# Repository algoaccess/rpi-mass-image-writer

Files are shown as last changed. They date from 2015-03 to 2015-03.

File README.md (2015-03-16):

# rpi-mass-image-writer
Raspberry Pi that writes to many USB drives at one go. Hardware buttons available to select the stored disk image to copy as well as to shutdown the device. 

Disk images are transferred to the Raspberry Pi via a Samba shared folder. The selected image is then written in parallel to all the drives at once using the ```dd```, ```pv``` and ```tee``` commands 

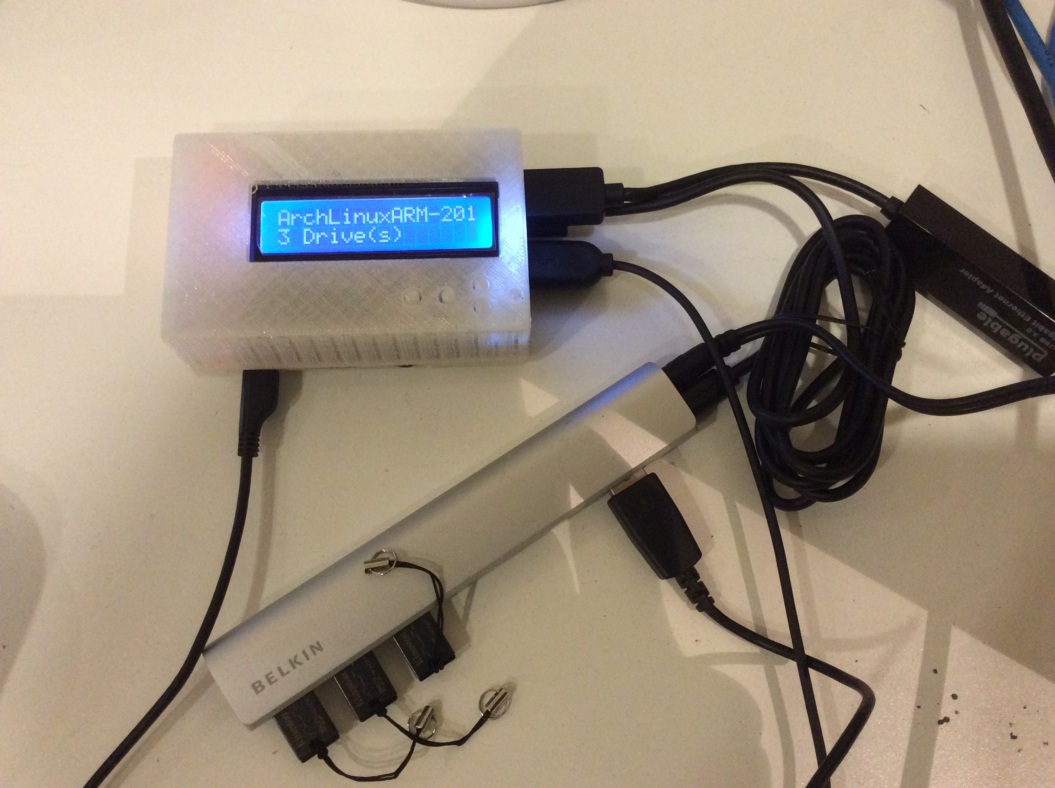
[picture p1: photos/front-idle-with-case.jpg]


Everything in with a nice 3D printed case.

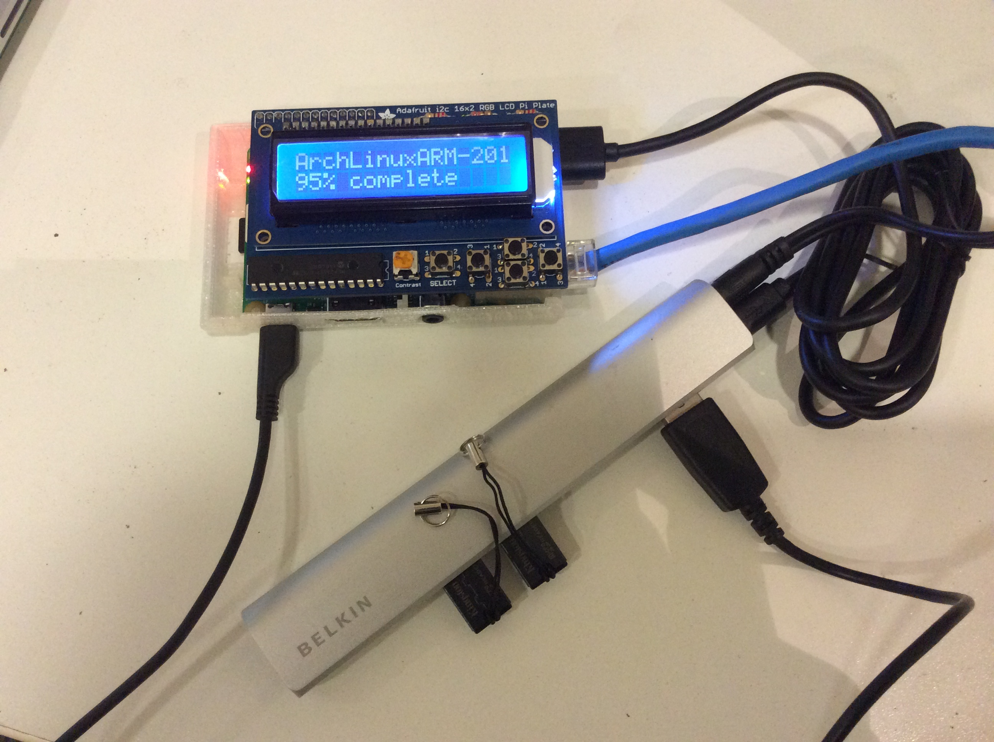
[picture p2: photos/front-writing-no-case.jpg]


The innards

#How to use?
1. Login to shared folder
2. Transfer image files via samba to shared folder
3. Plug in all USB flash drives to write to
4. Hit left button to enumerate all images and drives 
5. Use up/down buttons to select image
6. Press the right button to start writing to drives. You can press it again to terminate writing.
7. Press the select button (extreme left) to shutdown device properly to prevent data corruption. The words "Shutting down" will remain even after the device has completely shutdown, so just wait for the activity light to turn off before pulling the power.

#Hardware
1. Raspberry Pi 2 Model B (Others will work just as well)
2. Adafruit i2c 16x2 LCD Pi Plate with keypad
3. USB hubs (not all hubs are supported well, use the ones from this [list](http://elinux.org/RPi_Powered_USB_Hubs))
4. USB SD card adapters
5. USB Gigabit adapter (optional)

#Setting up

I use Arch Linux as it is stripped down and boots up far faster than Raspbian. With some modifications to the setup instructions, you can run this on Raspbian as well.

##Installing packages and configuring i2C

```bash
pacman -Syu python2 i2c-tools samba pv git

modprobe i2c-dev
echo "i2c-dev" > /etc/modules-load.d/i2c-dev.conf
```

On the latest versions of Arch Linux, it seems the i2c bus is disabled by default. We have to enable it. [Source](http://archlinuxarm.org/forum/viewtopic.php?f=31&t=8330)

```bash
nano /boot/config.txt

#Add the following lines
#Start
#If needed, replace the value below with "bcm2708-rpi-b.dtb" or "bcm2708-rpi-b-plus.dtb" depending on your Raspberry Pi type.
device_tree=bcm2709-rpi-2-b.dtb 
device_tree_param=i2c1=on
device_tree_param=spi=on
#End

reboot
```

##Clone this repo and run the app

```bash
git clone https://github.com/algoaccess/rpi-mass-image-writer.git
cd rpi-mass-image-writer
python2 writer.py
```
The LCD screen should now turn on.

##Setting up samba 

The folder we are sharing is the images directory.

```bash
nano /etc/samba/smb.conf
#Add/Modify the following lines to your smb.conf file between #start and #end
#Start
[global]
workgroup = WORKGROUP
server string = SD Duplicator
security = user
log file = /var/log/samba/%m.log
max log size = 50
dns proxy = no

[images]
path = /root/rpi-mass-image-writer/images
writable = yes
#End

#Create a user for samba
smbpasswd -a root
systemctl enable smbd
```

##Change hostname (optional)

In case you don't like the default ```alarmpi``` hostname.

```bash
hostnamectl set-hostname pi-usb-replicator
```

##Using a separate USB Gigabit adapter

Transfering large image files takes a long time on the internal 10/100 adapter so I opted to use a Gigabit adapter instead. Note that Pi is using just USB 2.0 with other devices sharing the bus so the speedup is only just about 2x instead of 10x faster which is still better than previously.

```bash
cp /etc/netctl/examples/ethernet-dhcp /etc/netctl/eth1
nano /etc/netctl/eth1

#Change the "Interface" value from eth0 to eth1

netctl enable eth1
reboot
#Test the network connection
```

##Starting on boot

```bash
cp /root/rpi-mass-image-writer/writer.service /etc/systemd/system/
systemctl enable writer.service
reboot
```

#References
1. [Open Source Image Duplicator](https://github.com/rockandscissor/osid)
2. [Adafruit Char Plate LCD](https://learn.adafruit.com/adafruit-16x2-character-lcd-plus-keypad-for-raspberry-pi/overview)
3. [i2c setup on Arch Linux](http://cfedk.host.cs.st-andrews.ac.uk/site/?q=2013-pi)
4. [Rpi 2 Model B 3D case top](http://www.thingiverse.com/thing:588608)
5. [Rpi 2 Model B 3D case bottom](http://www.thingiverse.com/thing:582366)
6. [Enable i2c on Arch Linux](http://archlinuxarm.org/forum/viewtopic.php?f=31&t=8330)
7. [dd to multiple drives](https://joshhead.wordpress.com/2011/08/04/multiple-output-files-with-dd-utility/)

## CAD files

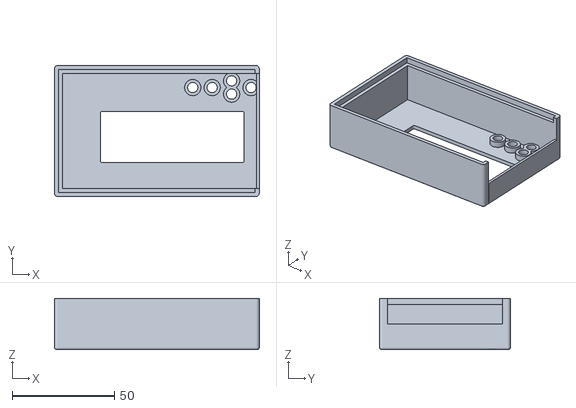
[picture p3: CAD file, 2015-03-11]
case/lcd-cover.stl
100.1 x 64.0 x 25.0

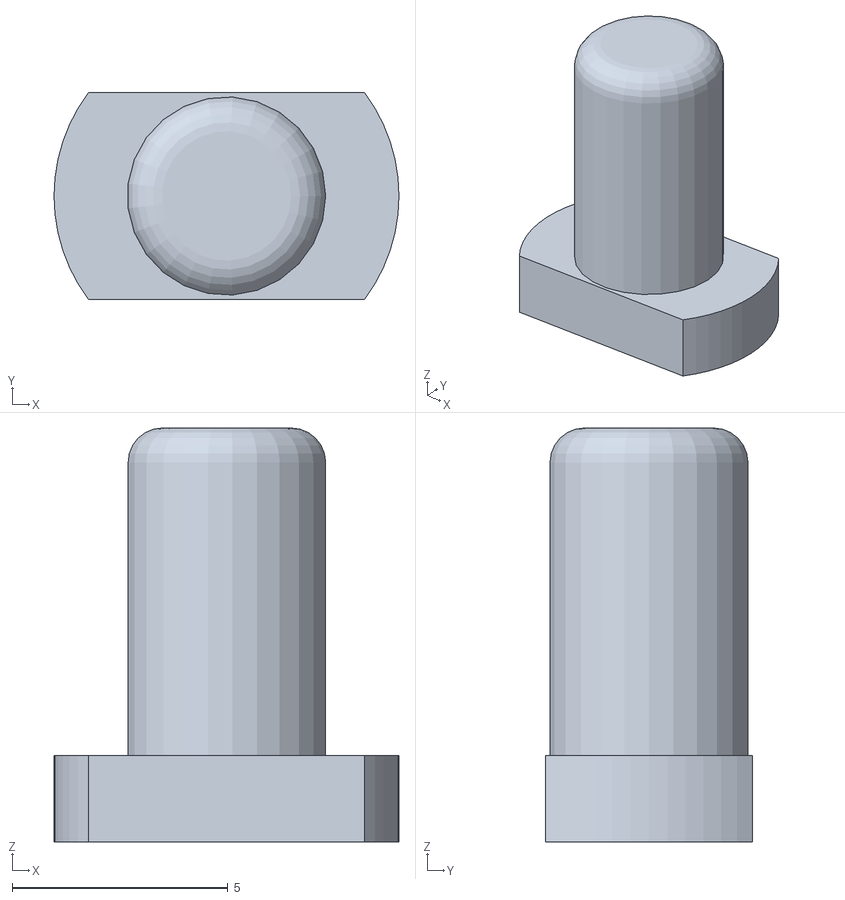
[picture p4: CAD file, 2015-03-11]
case/button.stl
8.00 x 4.80 x 9.60

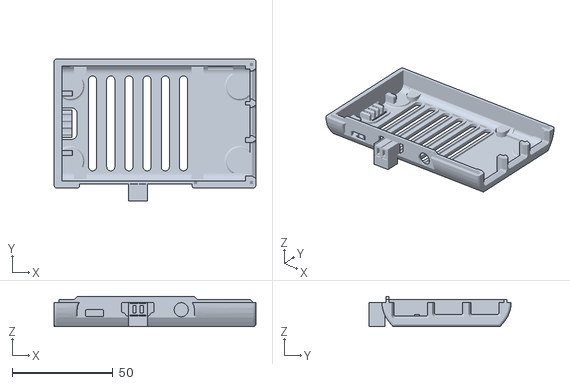
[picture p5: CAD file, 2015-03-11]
case/B+Base-Vented.stl
100.0 x 70.5 x 14.9

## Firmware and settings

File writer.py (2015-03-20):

import time
import shlex
import os
import subprocess
from threading import Thread
from os import listdir
from os.path import isfile, join
from subprocess import Popen, PIPE
from Adafruit_CharLCDPlate import Adafruit_CharLCDPlate

COLUMNS = 16
ROWS = 2
imagePath = "images/"

imageNames = []

currentImageSelection = 0
listOfDrives = []

writeStatusLine = ""

justCompleted = False
nowWriting = False
stopWritingNow = False

lastPressedTime = time.time()

lcd = Adafruit_CharLCDPlate()
lcd.begin(COLUMNS, ROWS)
lcd.clear()

def getConnectedDrives():
    commandOutput = runCommandAndGetStdout("lsblk -d | awk -F: '{print $1}' | awk '{print $1}'")
    splitted = commandOutput.splitlines()

    drives = []

    for drive in splitted:
        if drive != "NAME" and not drive.startswith("mmc"):
            drives.append(drive)
            

    return drives

def powerOff():
    lcd.clear()
    lcd.message("Shutting down...")
    runCommandAndGetStdout("poweroff")



def refreshSystem():
    global imageNames
    global listOfDrives

    filesfound = [ f for f in listdir(imagePath) if isfile(join(imagePath,f)) ]

    imageNames = []
    for file in filesfound:
        if file != ".gitignore":
            imageNames.append(file)


    currentImageSelection = 0;
    listOfDrives = getConnectedDrives()


def refreshLcd():
    numDrives = len(listOfDrives)
    numImages = len(imageNames)

    imageMessage = ""

    if numImages == 0:
        imageMessage = "No images found"
    else:
        imageMessage = imageNames[currentImageSelection]

    lcd.clear()

    driveMessage = ""

    if nowWriting:
        driveMessage = writeStatusLine + "% complete"
    else :
        if justCompleted :
            driveMessage = "Write complete!"
        else :
            driveMessage = str(numDrives) + " Drive(s)"

    lcd.setCursor(0, 0)
    lcd.message(imageMessage[:COLUMNS])
    print imageMessage

    lcd.setCursor(0, 1)
    lcd.message(driveMessage[:COLUMNS])
    print driveMessage




def runCommandAndGetStdout(cmd):
    proc = Popen(cmd, stdout=PIPE, stderr=PIPE, shell=True)
    out, err = proc.communicate()
    return out

def writeThreadFunction(arg):
    global nowWriting
    global writeStatusLine
    global stopWritingNow
    global justCompleted

    process = Popen(arg, stdout=PIPE, stderr=PIPE, shell=True, executable='/bin/bash')
    lines_iterator = iter(process.stderr.readline, b"")
    for line in lines_iterator:

        if stopWritingNow :
            runCommandAndGetStdout("killall pv")
            runCommandAndGetStdout("killall dd")
            process.kill()
            break


        line = line.rstrip()
        
        if line == "100" :
            line = "99" #To not give the impression that write has completed as the value stays at 100% for some time

        if writeStatusLine != line:
            writeStatusLine = line
            refreshLcd()



    if stopWritingNow :
        stopWritingNow = False
        justCompleted = False
    else :
        justCompleted = True

    nowWriting = False
    refreshLcd()


def writeImage():

    global nowWriting
    global writeStatusLine
    global stopWritingNow

    if len(imageNames) == 0 or len(listOfDrives) == 0:
        return

    imagingCommand = constructCommand()

    nowWriting = True
    stopWritingNow = False

    writeStatusLine = "0"
    refreshLcd()

    thread = Thread(target = writeThreadFunction, args = (imagingCommand, ))
    thread.start()




def constructCommand():
    command = "pv -n " + imagePath + "\"" +  imageNames[currentImageSelection] +  "\""
    numDrives = len(listOfDrives)

    firstDriveName = listOfDrives[0]
    firstDriveCommand = " | dd of=/dev/" + firstDriveName + " bs=1M"


    for i in range(1, numDrives):
        nextDriveCommand = " | tee >(dd of=/dev/" + listOfDrives[i] + " bs=1M)"
        command += nextDriveCommand


    command += firstDriveCommand
    print command
    return command



refreshSystem()
refreshLcd()

while True:
    time.sleep(0.01) #To prevent excessive CPU use
    currentTime = time.time()
    
    if (currentTime - lastPressedTime) >= 0.2:

        if lcd.buttonPressed(lcd.UP):
            lastPressedTime = currentTime
            
            if nowWriting :
                stopWritingNow = True
                continue


            if justCompleted :
                justCompleted = False
                continue
        
            currentImageSelection += 1
                
            if currentImageSelection >= len(imageNames):
                currentImageSelection = 0
            
            refreshLcd()

        elif lcd.buttonPressed(lcd.DOWN):
            lastPressedTime = currentTime
            
            if nowWriting :
                stopWritingNow = True
                continue

            if justCompleted :
                justCompleted = False
                continue

            currentImageSelection -= 1
        
            if currentImageSelection < 0:
                currentImageSelection = len(imageNames) - 1

            refreshLcd()


        if lcd.buttonPressed(lcd.LEFT):
            lastPressedTime = currentTime
            
            if nowWriting :
                stopWritingNow = True
                continue

            if justCompleted :
                justCompleted = False
                continue
        
            refreshSystem()
            refreshLcd()
    
        elif lcd.buttonPressed(lcd.SELECT):
            lastPressedTime = currentTime
            
            justCompleted = False
            powerOff()


        elif lcd.buttonPressed(lcd.RIGHT):
            lastPressedTime = currentTime
            
            if justCompleted :
                justCompleted = False
                continue
        
            if nowWriting :
                stopWritingNow = True
            else :
                writeImage()

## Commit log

2015-03-11 case pictures
    [B+Base-Vented.stl, button.stl, lcd-cover.stl]
2015-03-16 stop writing if any button is pressed except for shutdown button
2015-03-16 do not engage button if clearing write complete message
2015-03-16 another bug in write complete
    [writer.py]
2015-03-16 more responsive button press
